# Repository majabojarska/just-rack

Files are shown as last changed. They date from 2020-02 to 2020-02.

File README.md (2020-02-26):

# JustRack

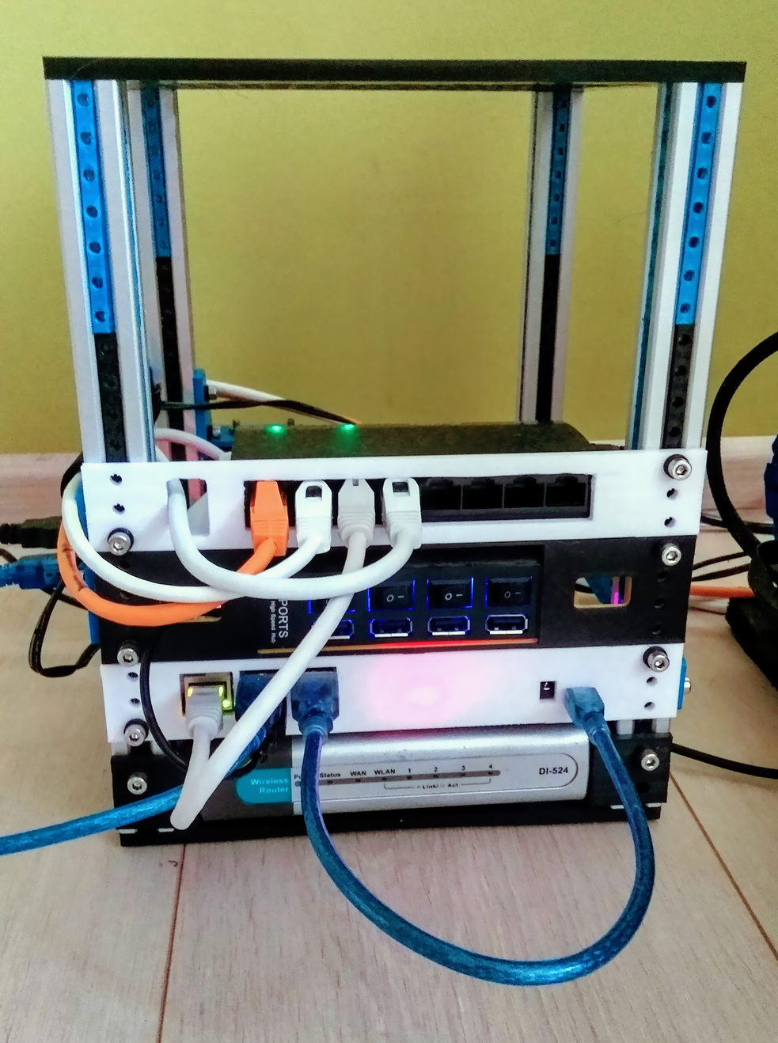
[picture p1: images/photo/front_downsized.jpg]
Photo of JustRack up and running.


## Table of Contents

- [JustRack](#justrack)
  - [Table of Contents](#table-of-contents)
  - [About](#about)
    - [Credits](#credits)
  - [Software](#software)
  - [Hardware](#hardware)
    - [Store-bought](#store-bought)
    - [3D printed](#3d-printed)
      - [Recommended FDM print settings:](#recommended-fdm-print-settings)
    - [Tools](#tools)
  - [OpenSCAD scripts](#openscad-scripts)
    - [Mounting rail](#mounting-rail)
    - [Rack module](#rack-module)
    - [Side support](#side-support)
  - [Custom modules](#custom-modules)
    - [Design guidelines](#design-guidelines)
      - [Front plate example](#front-plate-example)
      - [Base plate](#base-plate)
    - [Available custom modules](#available-custom-modules)

## About

JustRack is a compact and modular enclosure for housing electronic modules.
This design allows for customization in terms of width, depth and length. Custom modules can be designed according to a couple simple design rules (see "Custom modules" section). This page assumes 200mm width and depth.

### Credits

This project was inspired by [6" Rack Enclosure, Customizable by KronBjorn](www.thingiverse.com/thing:1936196) on Thingiverse.

---

## Software

- OpenSCAD - for generating parametric models from the provided scripts.
- Fusion 360 (optional, personal choice) - custom modules design.

## Hardware

My main goal was to make the design as accesible as possible. That's why I chose V-Slot rails, as they are commonly available. T-Slot is also a possibility, but keep in mind that the included [OpenSCAD script for mounting rail generation](models/scad/mounting_rail.scad) is intented for V-Slot (I might add a T-Slot design in the future).

### Store-bought

| Part | Amount (pcs) | Note |
| :--- | :--- | :--- |
| OpenBuilds V-Slot 20x20 Linear Rail | 4 | Any length is fine |
| M5 screw | 8 | Top and bottom frames |
| M4 screw | As needed | Module mounting, can be longer. |
| 10x3mm rubber feet | 4 | Can be higher than 3mm |

- Socket head hex screws are a personal preference, other types of screw heads will also work. The benefit of using socket head hex screw is that the bottom of the head is flat, so they don't bite into the mounting rail surface. Shims might be used to adapt screws with other types of screw head.
- Longer module mounting screws (M4), may require placing a shim between the screw head and module front plate, to fill the excess space.

### 3D printed

| Part ID | Amount (pcs) |
| :--- | :--- |
| Bottom cover | 1 |
| Top cover | 1 |
| External sides mounting rails | 8 |
| Internal sides mounting rails (optional) | 8 |
| M4 screw shims | As needed |

#### Recommended FDM print settings:

- 0.2mm layer height
- 0.4mm nozzle

### Tools

- 3D printer with build plate of at least 20x20cm in size. Please take the potentially additional brim/skirt space into account.
- Screwdriver/hex keys.
- 5mm screw tap.

---

## OpenSCAD scripts

### Mounting rail

Designed for slots in V-Slot linear rails. Generated based on specified length (mm), which should be equal to the length of the chosen V-Slot rail.

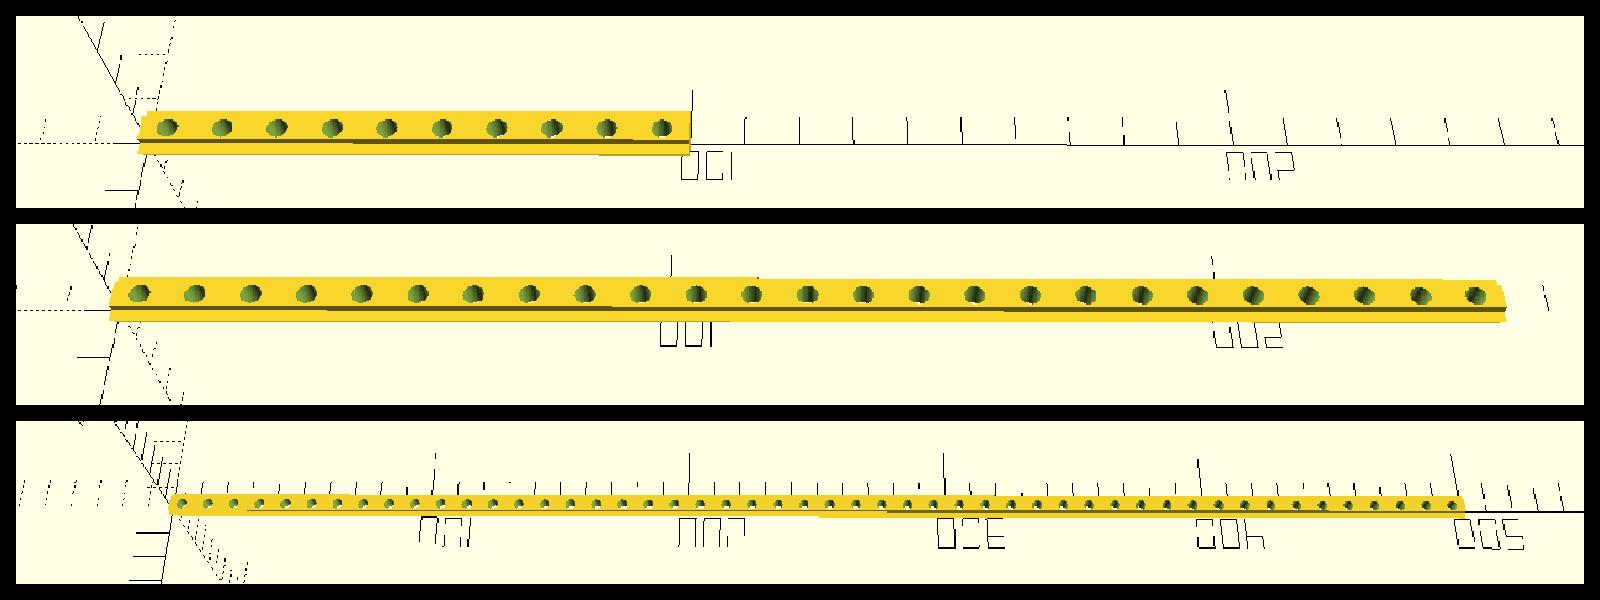
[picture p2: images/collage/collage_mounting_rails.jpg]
Collage of generated mounting rails.


### Rack module

Generates a generic rack module consisting of a front and base plate.

Customizable parameters:

- module height (units),
- front plate thickness (mm),
- base plate length (mm),
- base plate thickness (mm).

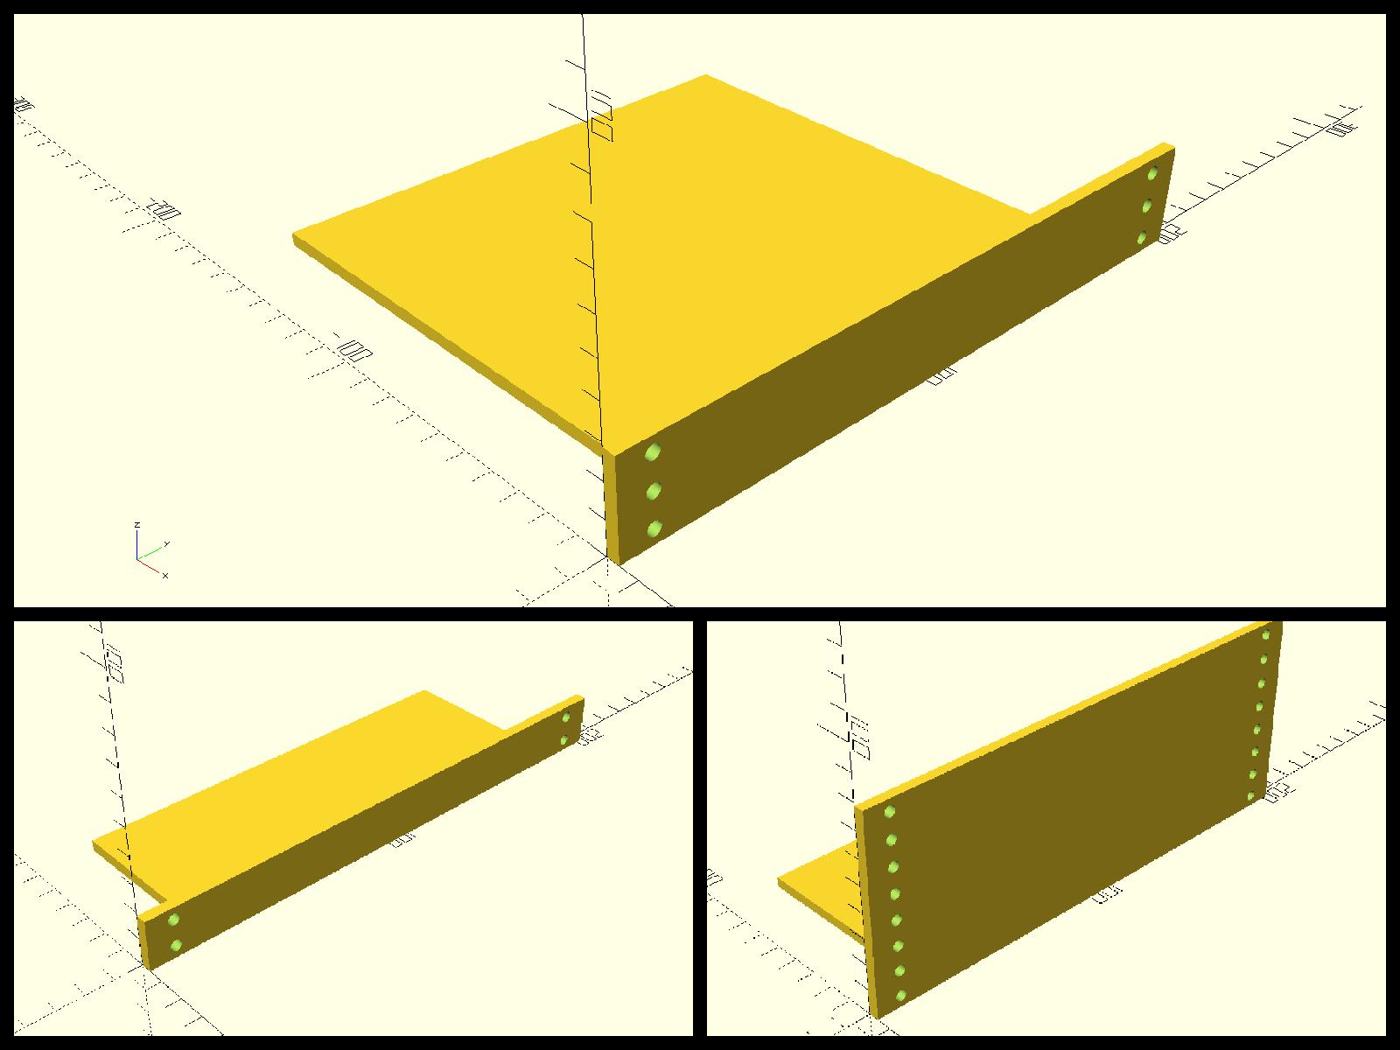
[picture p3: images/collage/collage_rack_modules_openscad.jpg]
Collage of generated mounting rails.


### Side support

Generates a part for supporting longer and/or heavier modules on the side that is opposite to their front panel. May be also used to mount miscallenous parts or routing cables.

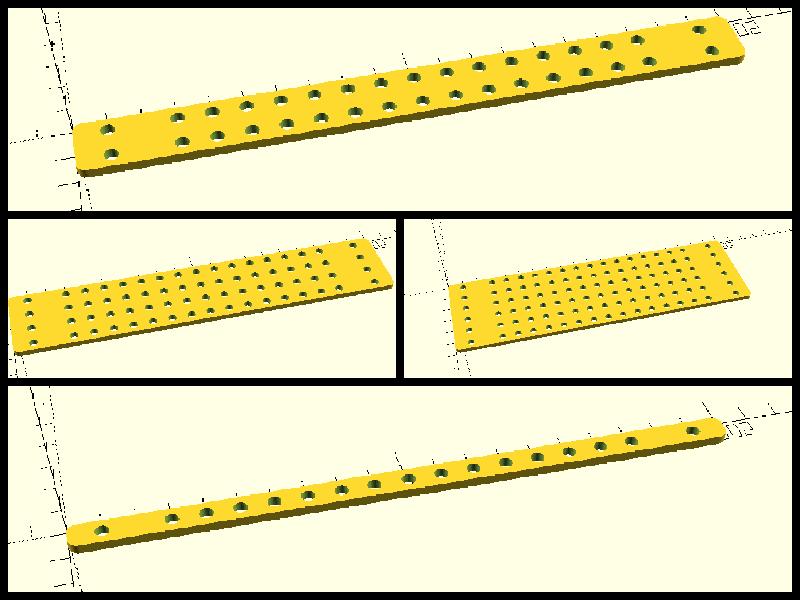
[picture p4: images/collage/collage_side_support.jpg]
Side support collage


## Custom modules

### Design guidelines

Requirements for custom module design:

| Constraint | Values |
| --- | --- |
| Front plate width | 200mm |
| Front plate height | 10mm\*n - 1mm from top and bottom |
| Front plate screwhole position | Vertical spacing between hole centers = 10mm |
| Screw hole diameter | Equal to bracket screw size + ~0.2mm |
| Inner module width | <=158mm |
| Module length (behind front plate) | 200mm |

#### Front plate example

Height of this plate is 3 units - 0.6mm offsets from top and bottom sides. This is to avoid adjacent modules from colliding, as designing for 0mm spacing will cause trouble on mounting.

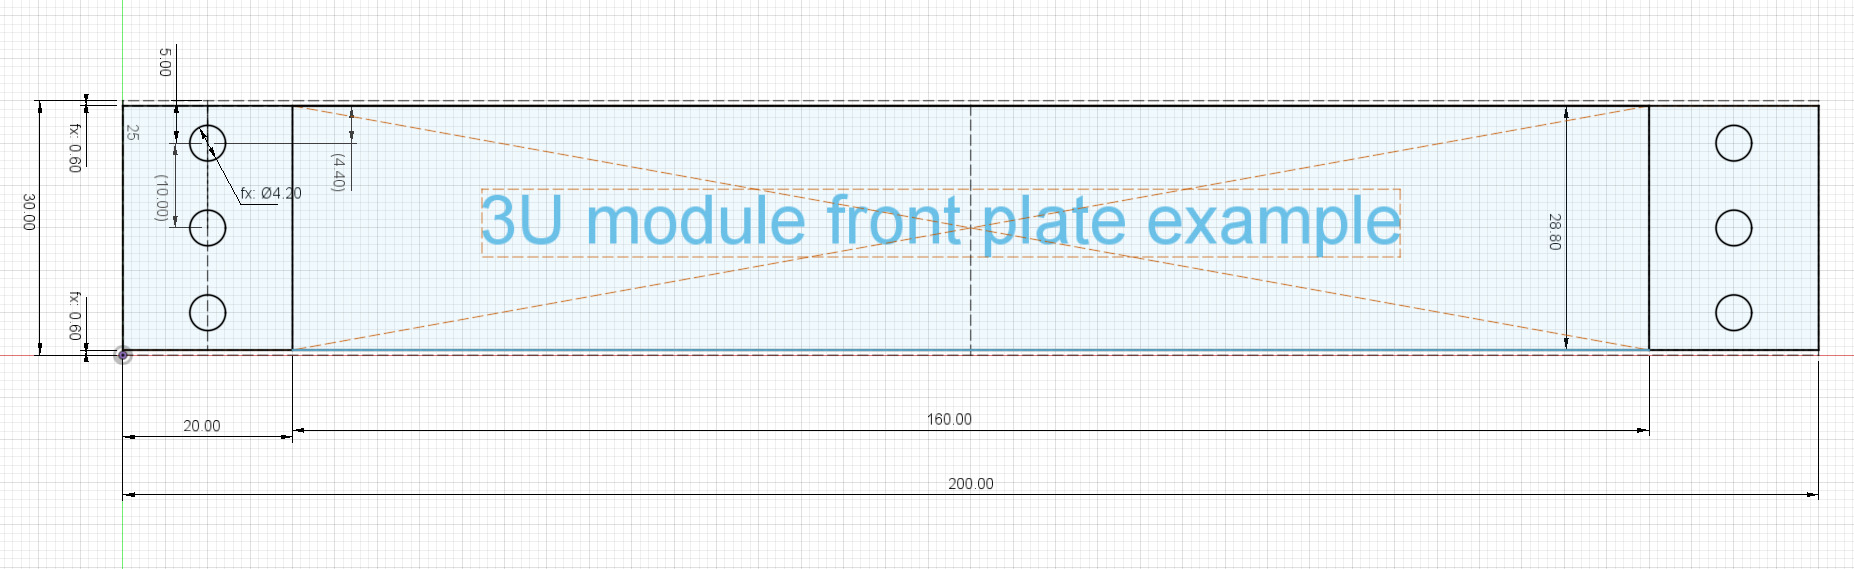
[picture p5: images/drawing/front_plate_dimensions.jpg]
Front plate design guidelines


#### Base plate

Base plate should leave at least 1mm of empty space between itself and the V-Slot rails, to avoid excess friction and pressure.

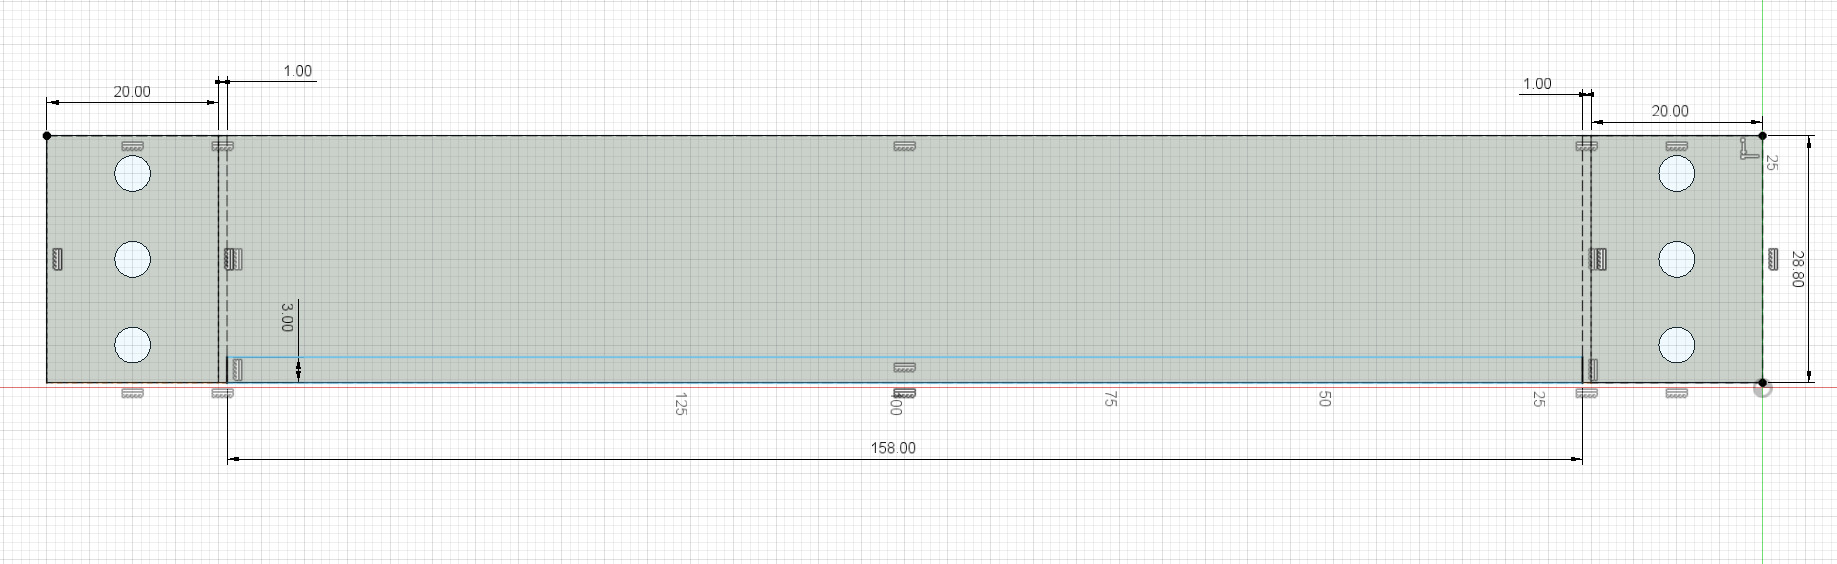
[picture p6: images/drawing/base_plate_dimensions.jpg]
Base plate design guidelines


Base plate extrusion should not exceed the rack's depth (200mm).

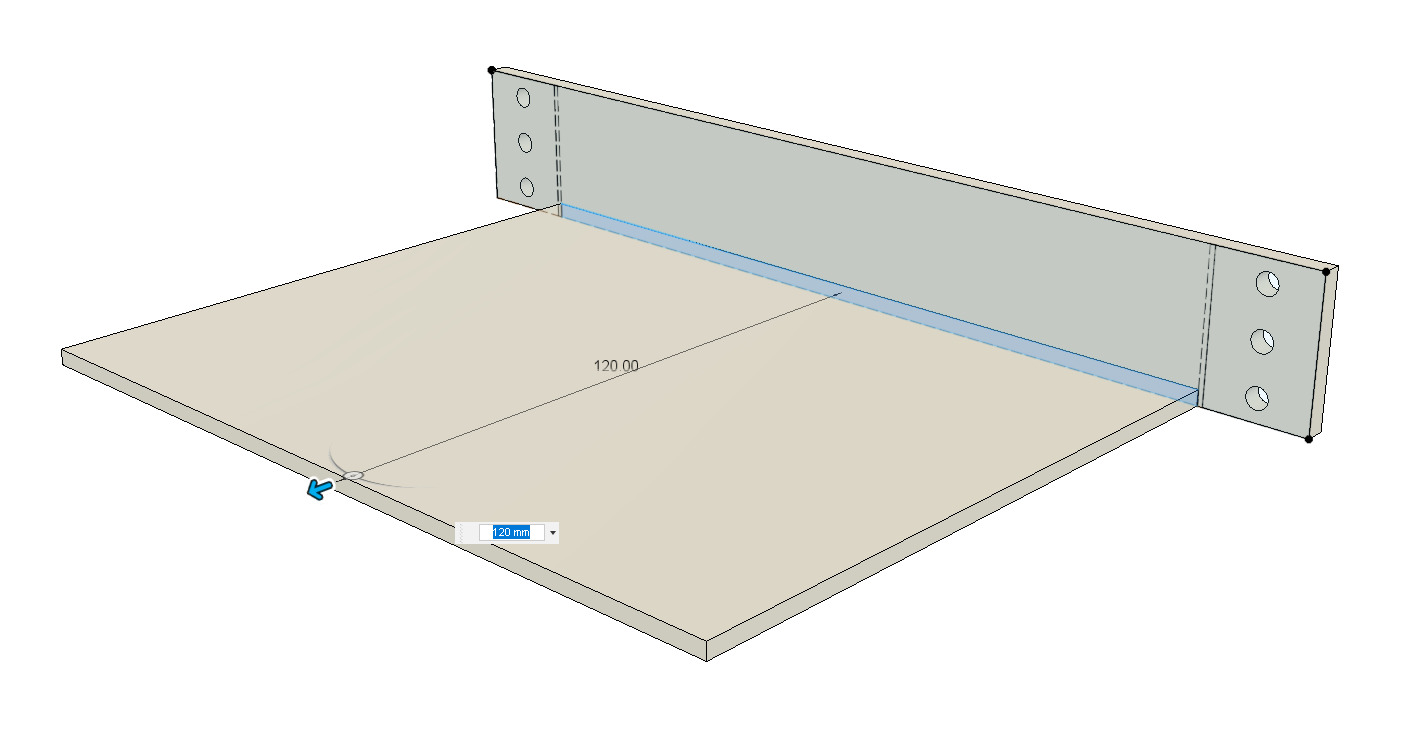
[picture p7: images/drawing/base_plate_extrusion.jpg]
Base plate extrusion


An optional, but recommended addition are reinforcements for the connection between front and base plate.

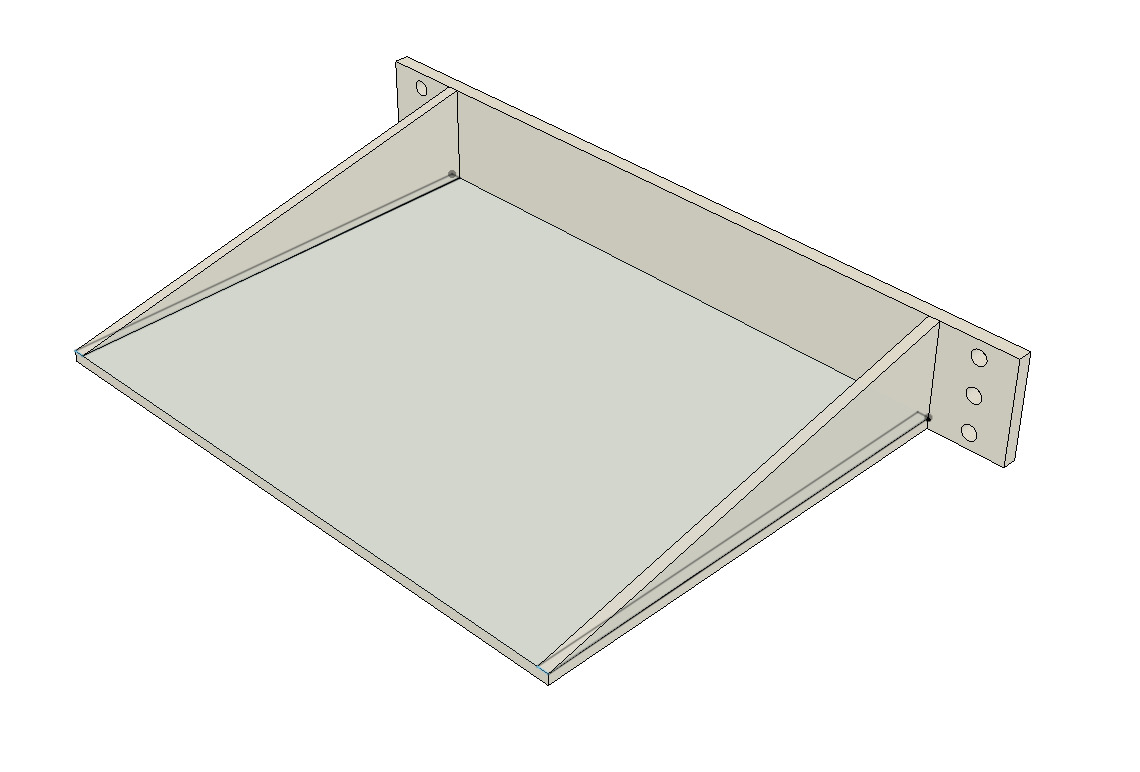
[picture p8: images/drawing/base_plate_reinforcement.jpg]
Base plate reinforcement


### Available custom modules

All the available custom modules with their descriptions are available in the [modules](modules) directory.

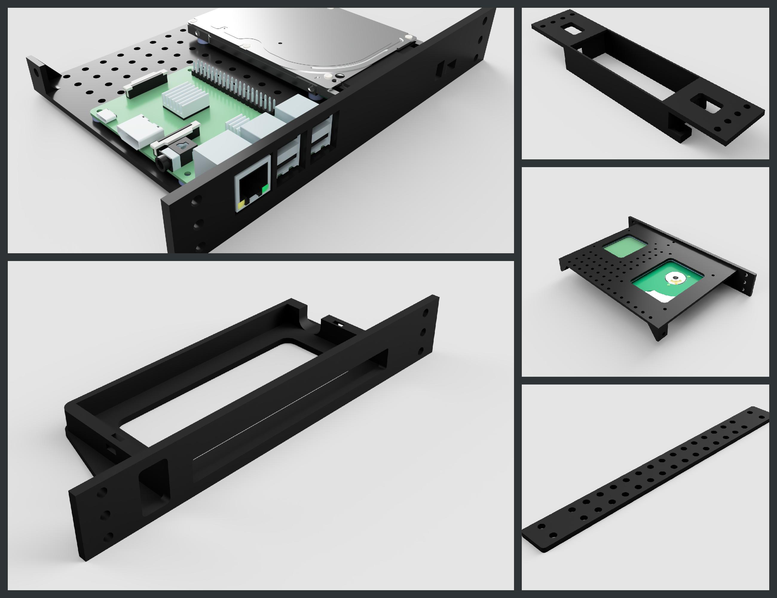
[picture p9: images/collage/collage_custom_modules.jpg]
Collage of custom module images


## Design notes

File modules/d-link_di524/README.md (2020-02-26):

# D-Link DI-524 module

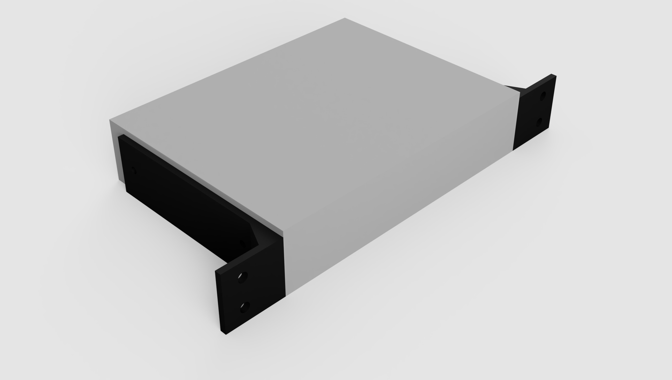
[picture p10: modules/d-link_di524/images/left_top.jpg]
D-Link DI-524 module render


## About

This module requires drilling additional holes for 3mm mounting screws in the device's enclosure.

## Models

- [F3D](models/f3d)
- [STEP](models/step)
- [STL](models/stl)

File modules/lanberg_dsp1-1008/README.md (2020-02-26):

# Lanberg DSP1-1008 module

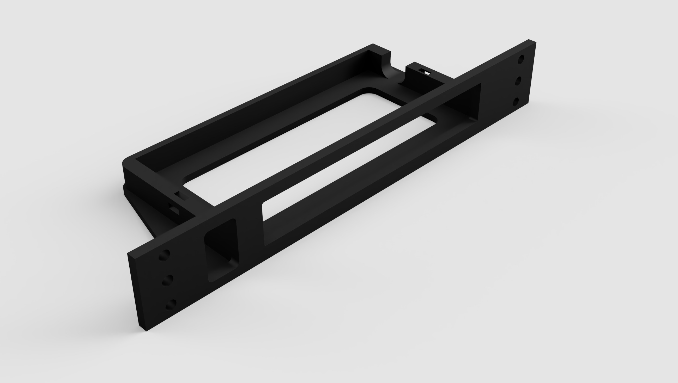
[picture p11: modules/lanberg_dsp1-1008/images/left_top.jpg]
Lanberg DSP1-1008 module render


## About
After printing, the device should pop in place with some force. This might vary depending on the used 3d printer. In case the switch is loose inside the module, there are holes on the sides to hold it down with a zip tie.

## Models

- [F3D](models/f3d)
- [STEP](models/step)
- [STL](models/stl)

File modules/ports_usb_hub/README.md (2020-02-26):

# Ports USB hub module

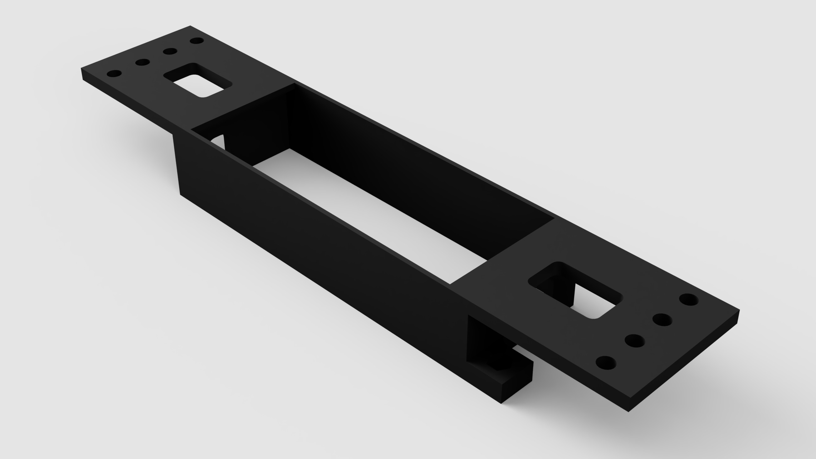
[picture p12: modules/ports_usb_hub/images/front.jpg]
Ports USB hub module render, front


## About

This is a custom module for housing a [4-port USB hub by PORTS](images/ports_hub.jpg).

The back cover requires 2xM3 screws with nuts.

## Models

- [F3D](models/f3d)
- [STEP](models/step)
- [STL](models/stl)

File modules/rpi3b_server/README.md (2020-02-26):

# Raspberry Pi 3B server module

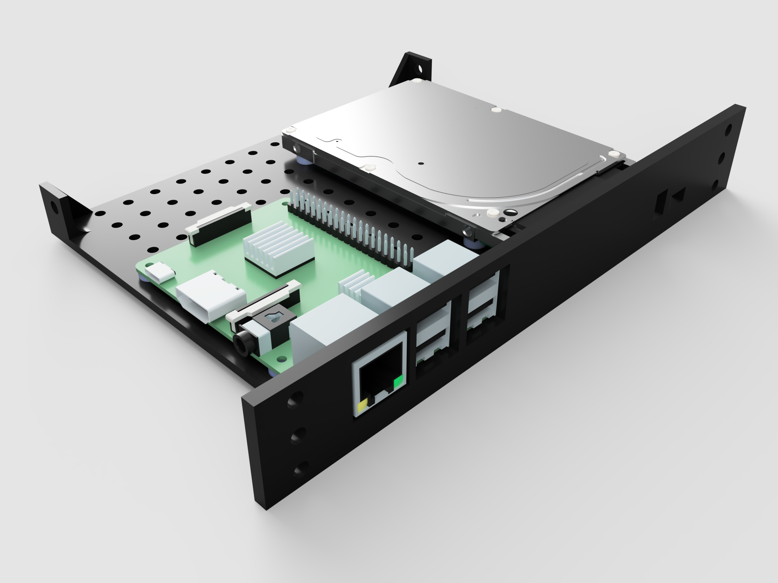
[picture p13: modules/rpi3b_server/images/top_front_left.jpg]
Raspberry Pi 3B server module render


## About

This is a custom module for housing a Raspberry Pi 3B and an external 2.5" HDD with a USB adapter. As this module is longer and heavier, it is recommended to use a side support on one side of the module.

## Models

- [F3D](models/module/f3d)
- [STEP](models/module/step)
- [STL](models/module/stl)

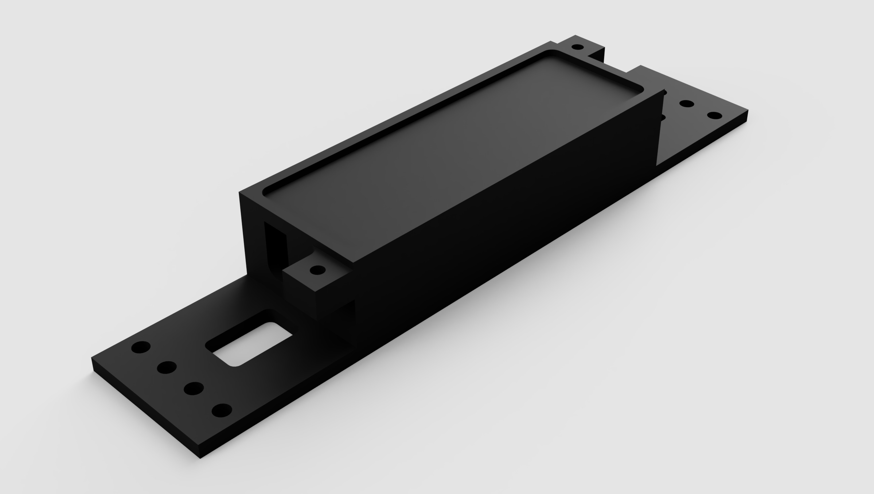
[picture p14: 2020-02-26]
modules/ports_usb_hub/images/back_with_cover.jpg

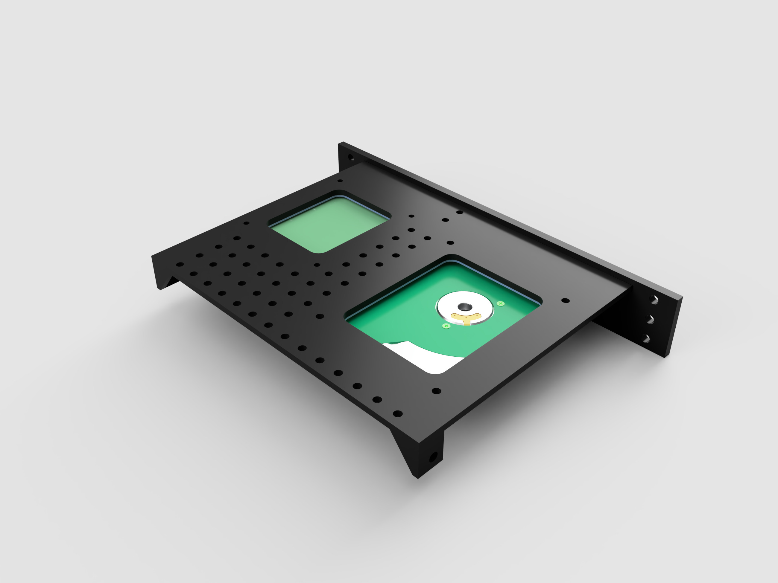
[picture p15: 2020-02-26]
modules/rpi3b_server/images/bottom.jpg

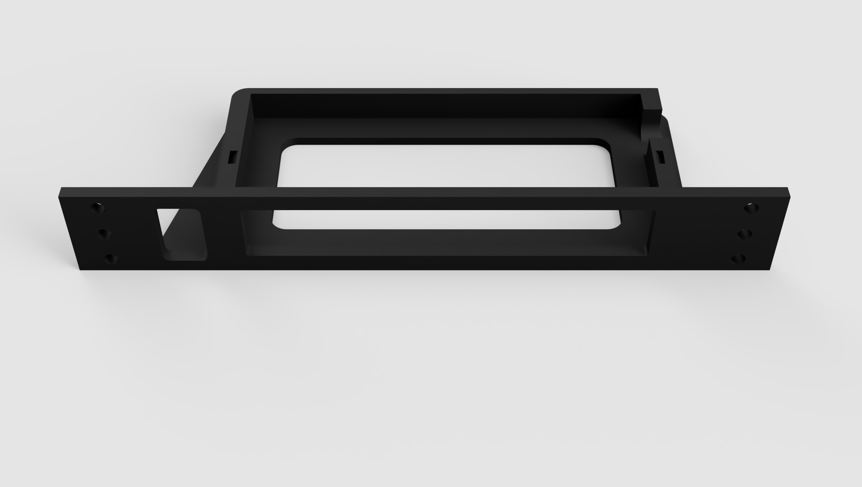
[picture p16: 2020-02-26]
modules/lanberg_dsp1-1008/images/front_top.jpg

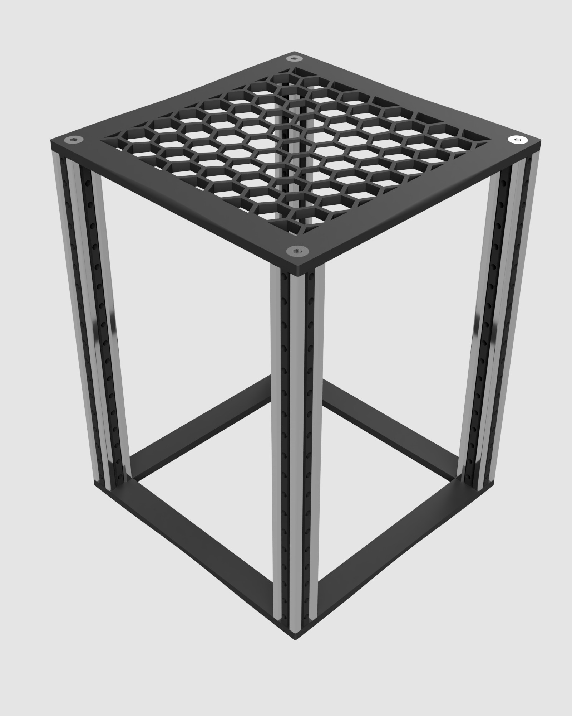
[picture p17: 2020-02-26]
images/render/top_corner.jpg

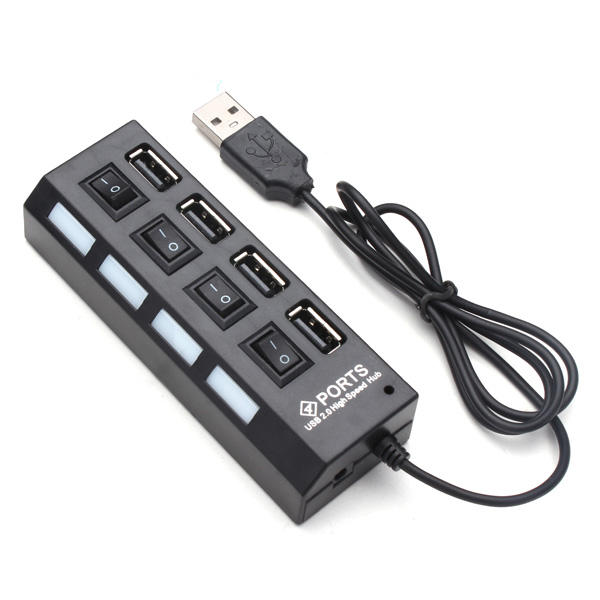
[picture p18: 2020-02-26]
modules/ports_usb_hub/images/ports_hub.jpg

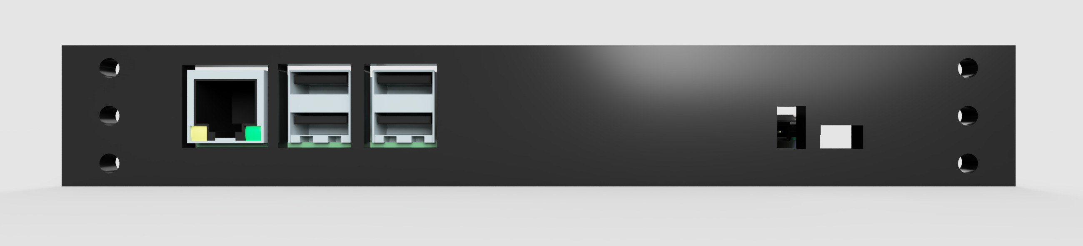
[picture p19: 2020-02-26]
modules/rpi3b_server/images/front.jpg

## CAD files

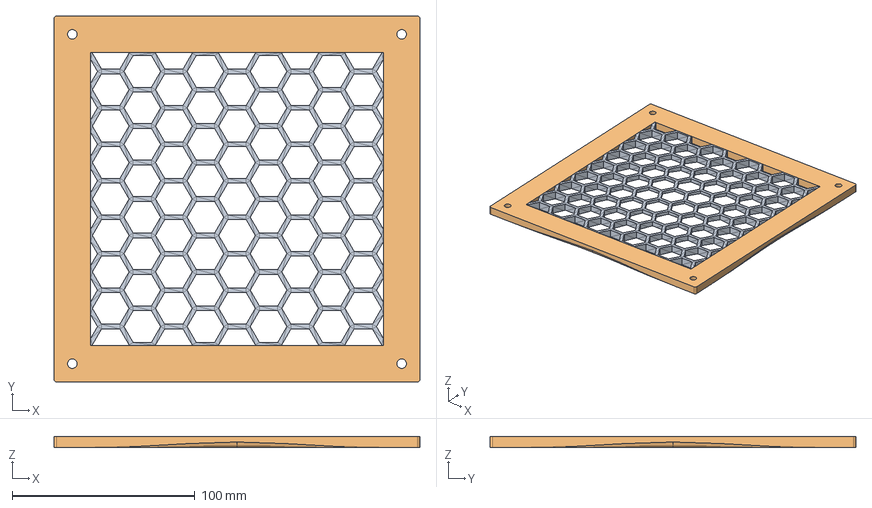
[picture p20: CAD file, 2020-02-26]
models/step/frame_top.step
200.0 x 200.0 x 6.03 mm

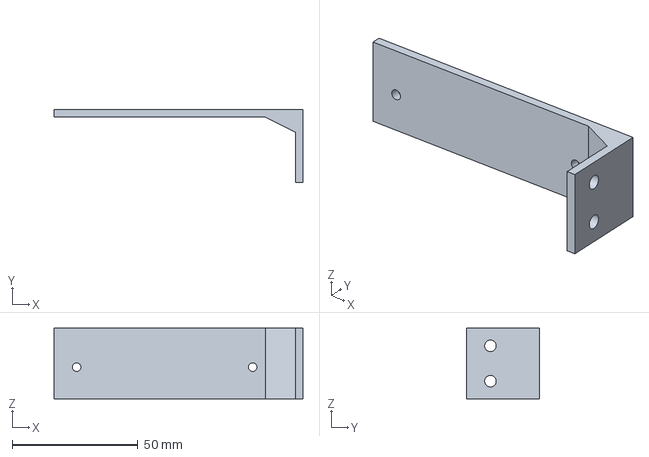
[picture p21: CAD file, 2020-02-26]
modules/d-link_di524/models/step/bracket_right.step
99.0 x 29.0 x 28.1 mm

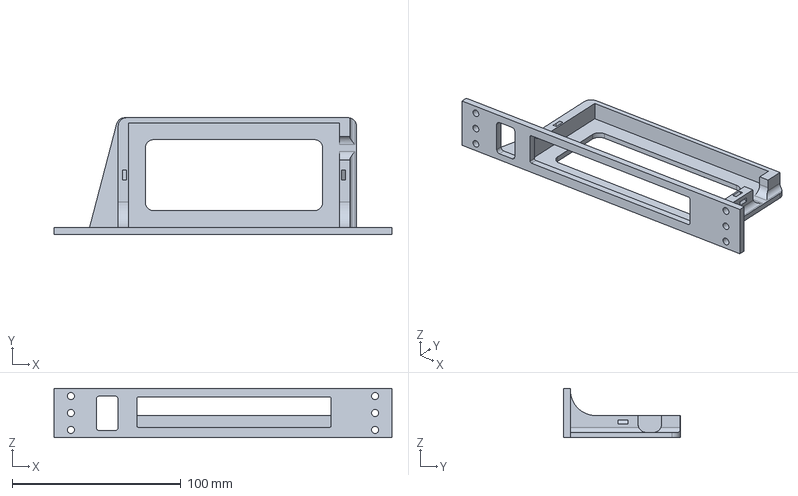
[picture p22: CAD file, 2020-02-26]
modules/lanberg_dsp1-1008/models/step/module_lanberg_dsp1-1008.step
200.0 x 69.0 x 29.0 mm

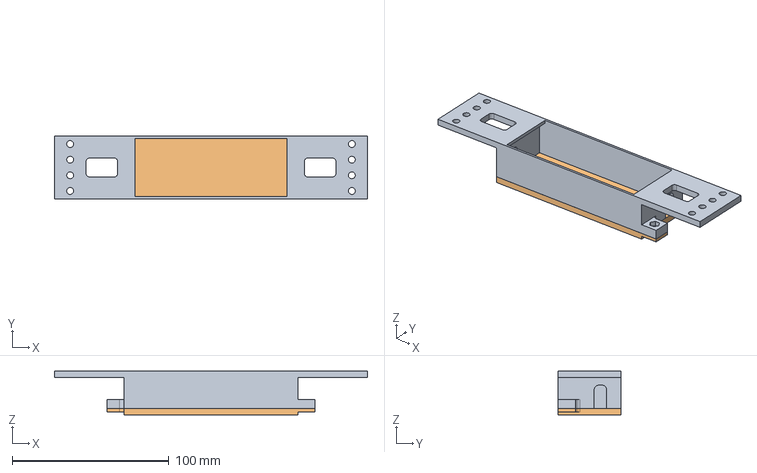
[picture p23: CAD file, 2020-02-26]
modules/ports_usb_hub/models/step/ports_usb_hub.step
200.0 x 40.0 x 28.0 mm
Front
Back plate

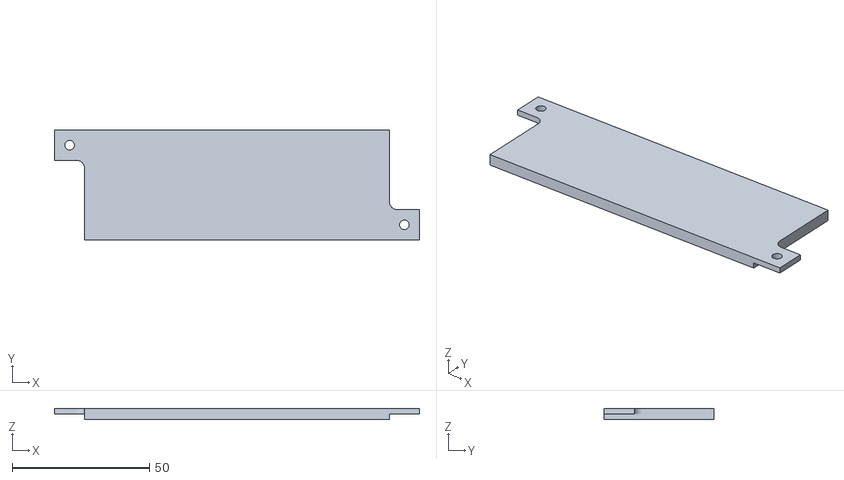
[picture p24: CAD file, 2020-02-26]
modules/ports_usb_hub/models/stl/cover_back.stl
133.0 x 40.0 x 4.00

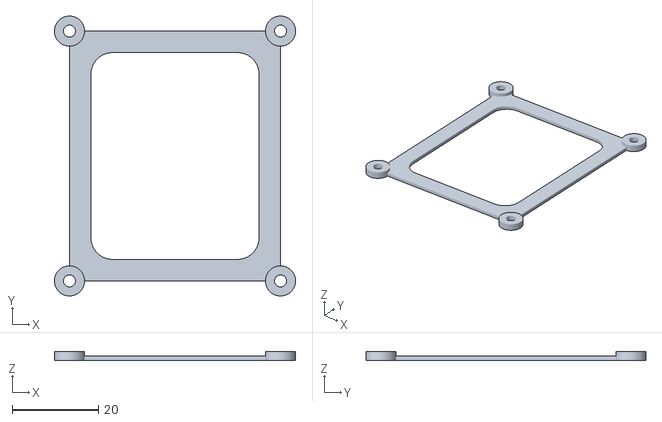
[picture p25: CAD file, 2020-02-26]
modules/rpi3b_server/models/module/stl/standoff_rpi.stl
56.0 x 65.0 x 2.00

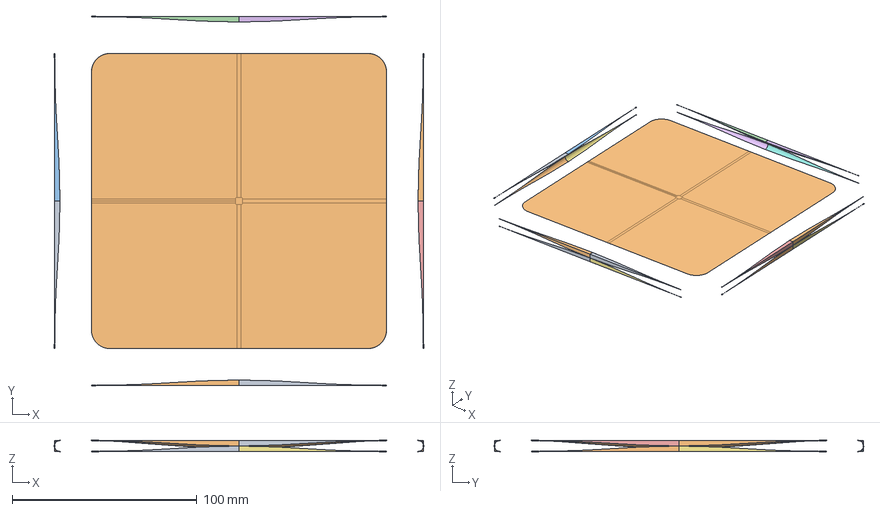
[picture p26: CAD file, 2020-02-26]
models/step/cutouts.step
200.0 x 200.0 x 6.00 mm
Top
Bottom
CurvedCutout

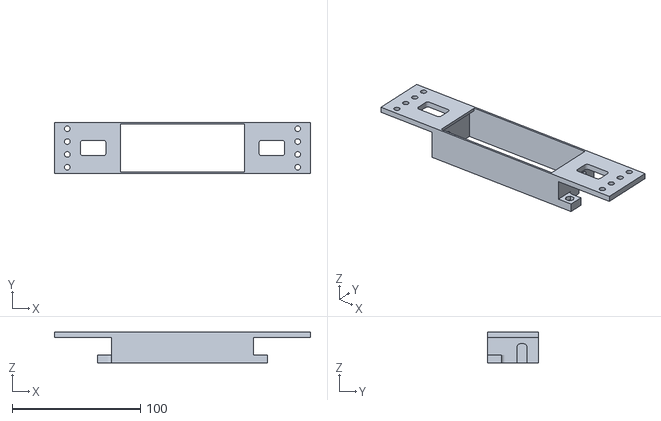
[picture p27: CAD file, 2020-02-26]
modules/ports_usb_hub/models/stl/front.stl
200.0 x 40.0 x 24.0

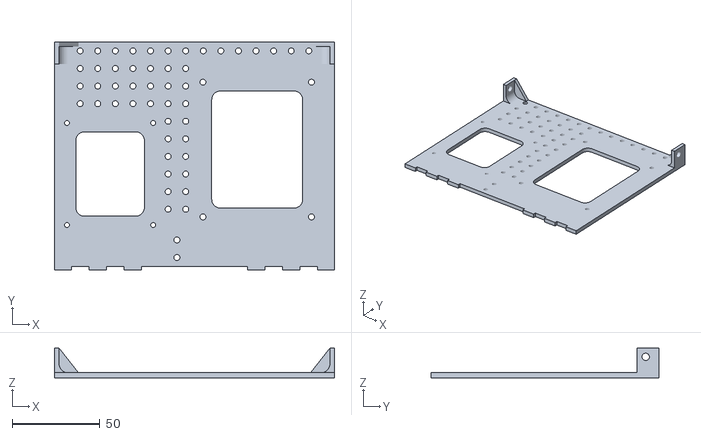
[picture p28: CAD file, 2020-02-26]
modules/rpi3b_server/models/module/stl/base.stl
159.2 x 129.5 x 17.0

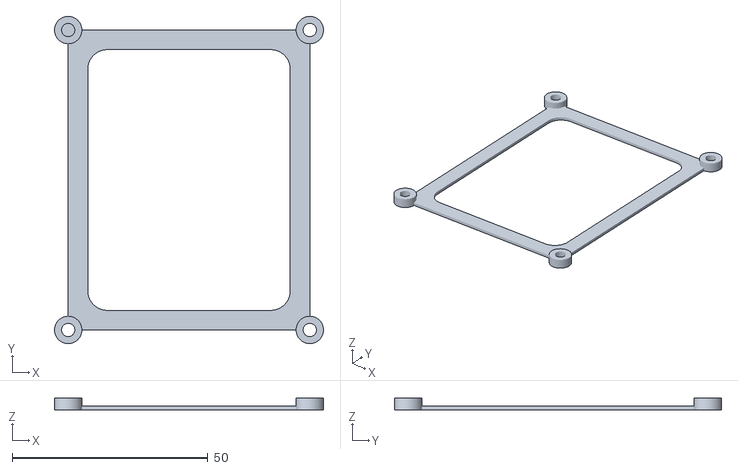
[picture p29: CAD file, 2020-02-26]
modules/rpi3b_server/models/module/stl/standoff_hdd.stl
68.7 x 83.6 x 3.00

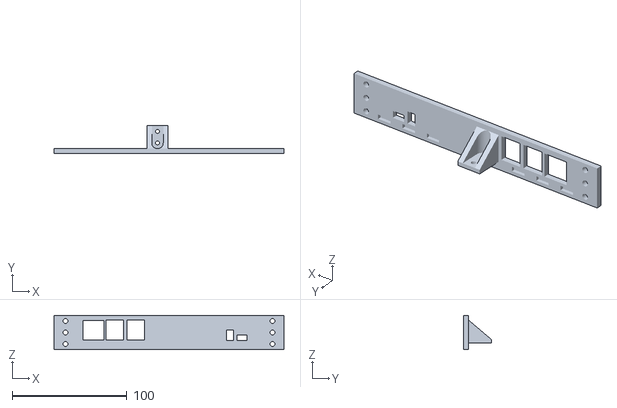
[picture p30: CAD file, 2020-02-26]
modules/rpi3b_server/models/module/stl/front.stl
200.0 x 24.0 x 29.6

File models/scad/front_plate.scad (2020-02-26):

$fn = 50;

// Customizable settings
front_plate_thickness = 4;
front_plate_units = 3;

// Constants
m4_screw_hole_loose_diam = 4.2;
unit_len = 10; // 1U = 10mm
v_slot_size = 20; // 20x20mm V-Slot
rack_width = 200;
edge_offset = 0.6; // Top/bottom edge additional empty space

// Front plate generation
front_plate(front_plate_units, front_plate_thickness);

module front_plate(unit_count, thickness){
    difference(){
        union(){
            plate_height = unit_len*unit_count - edge_offset*2;
            cube([plate_height,rack_width,thickness]);
        }                        
        for(i=[1:unit_count]){ // Screw holes
            translate([-edge_offset,0,0])
            union(){
            translate([unit_len*i-unit_len/2,v_slot_size/2,-1]){
                cylinder(d=m4_screw_hole_loose_diam,h=thickness+2);
            } 
            translate([unit_len*i-unit_len/2,rack_width-v_slot_size/2,-1]){
                cylinder(d=m4_screw_hole_loose_diam,h=thickness+2);
            }       
            }               
        }
    }
}

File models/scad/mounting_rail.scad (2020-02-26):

$fn = 50;

// Customizable settings
mounting_rail_length = 500;

// Constants
m4_screw_hole_diam = 3.8;
unit_len = 10; // 1U = 10mm

// Mounting rail generation
mounting_rail(unit_count=mounting_rail_length/unit_len);

module mounting_rail(unit_count){
    difference(){
        union(){
            translate([-2.4,0,4]){ // Top
                cube([4.8,unit_len*unit_count,1.5]);
            }    
            translate([-2.4,unit_len*unit_count,0]){ // Bottom polygon extrusion
                rotate([90,0,0]){
                    linear_extrude(unit_len*unit_count){
                        polygon(points=[[0,0],[4.8,0],[7,4],[-2.2,4]]);
                    }
                }
            }
        }                        
        for(i=[1:unit_count]){ // Screw holes
            translate([0,unit_len*i-unit_len/2,-1]){
                cylinder(d=3.8,h=10);
            }                       
        }
    }
}

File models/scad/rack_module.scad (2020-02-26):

$fn = 50;

use <front_plate.scad>

// Customizable settings
front_plate_thickness = 4;
front_plate_units = 2;
base_plate_length = 60;
base_plate_thickness = 4;

// Rack module generation
rack_module(
    front_plate_units, 
    front_plate_thickness, 
    base_plate_length, 
    base_plate_thickness
);

// Constants
m4_screw_hole_loose_diam = 4.2;
unit_len = 10; // 1U = 10mm
v_slot_size = 20; // 20x20mm V-Slot
rack_width = 200;
edge_offset = 0.6; // Top/bottom edge additional empty space
base_plate_side_offset = 1;

module rack_module(
    front_plate_units, 
    front_plate_thickness,
    base_plate_length,
    base_plate_thickness
){
    union(){
        // Front plate
        translate([front_plate_thickness,0,0])
        rotate([0,-90,0])
        front_plate(front_plate_units, front_plate_thickness);

        // Base plate
        base_plate_width = rack_width - 2*v_slot_size - 2*base_plate_side_offset;
        base_plate_left_side_offset = v_slot_size+base_plate_side_offset;
        translate([-base_plate_length,base_plate_left_side_offset,0])
        cube([
            base_plate_length,
            base_plate_width,
            base_plate_thickness
        ]);
    }
}

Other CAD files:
modules/d-link_di524/models/stl/bracket_left.stl
modules/lanberg_dsp1-1008/models/stl/mount.stl
models/step/frame_bottom.step
models/scad/side_support.scad
models/f3d/cutouts.f3d
models/f3d/frame_bottom.f3d
models/f3d/frame_top.f3d
models/stl/frame_bottom.stl
models/stl/frame_top.stl
modules/d-link_di524/models/f3d/bracket_left.f3d
modules/d-link_di524/models/f3d/bracket_right.f3d
modules/d-link_di524/models/stl/bracket_right.stl
modules/lanberg_dsp1-1008/models/f3d/module_lanberg_dsp1-1008.f3d
modules/ports_usb_hub/models/f3d/ports_usb_hub.f3d
modules/rpi3b_server/models/dummy/RPi3.f3d
